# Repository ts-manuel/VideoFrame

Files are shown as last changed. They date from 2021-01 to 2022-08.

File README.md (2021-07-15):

# Video Frame


<!-- TABLE OF CONTENTS -->
<details open="open">
  <summary>Table of Contents</summary>
  <ol>
    <li>
      <a href="#about-the-project">About The Project</a>
    </li>
    <li>
      <a href="#getting-started">Getting Started</a>
      <ul>
        <li><a href="#prerequisites">Prerequisites</a></li>
        <li><a href="#compiling">Compiling</a></li>
        <li><a href="#usb-bootloader">USB Bootloader</a></li>
      </ul>
    </li>
    <li><a href="#how-to-operate">How to Operate</a></li>
      <ul>
        <li><a href="#circuit-diagram">Circuit Diagram</a></li>
        <li><a href="#buttons">Buttons</a></li>
        <li><a href="#configuration-through-usb">Configuration through USB</a></li>
      </ul>
    <li><a href="#disclaimer">Disclaimer</a></li>
  </ol>
</details>

<!-- ABOUT THE PROJECT -->
## About The Project
This is a digital picture frame that plays movies at one frame per minute. Images appear on a [7-Color ePaper display](https://www.waveshare.com/5.65inch-e-paper-module-f.htm). The whole movie is stored as a sequence of jpeg images on an SD-Card. An STM32 microcontroller does the jpeg decoding and drives the display.

e-Paper displays maintain the displayed image without needing any power. The image is updated every 24 minutes and an update cycle takes 18 seconds. Since the device is in sleep mode for the majority of the time, power draw is minimal and the batteries last for a decent amount of time.

The device is powered by 6 AA batteries.

For more info check out the [full log on hackaday.io](https://hackaday.io/project/177197-the-slowest-video-player-with-7-colors)

<!-- GETTING STARTED -->
## Getting Started
### Prerequisites
* [STM32CubeIDE 1.4.0](https://www.st.com/en/development-tools/stm32cubeide.html)
* [dfu-util](http://dfu-util.sourceforge.net/)

### Compiling
* Open STM32CubeIDE
* Select a folder as workspace (this can be any folder in your hard-drive)
* Click on `File > Import`
* Select `General > Existing Project into Workspace` then click next
* Browse for the folder `stm32` select the project and click finish

### USB bootloader
* Connect the USB cable, check that the [correct drivers](https://www.hanselman.com/blog/how-to-fix-dfuutil-stm-winusb-zadig-bootloaders-and-other-firmware-flashing-issues-on-windows) are installed
* Enter DFU mode by pressing the RESET while holding down the BOOT button
* Use the following command to flash the firmware

      dfu-util -a0 -s 0x08000000 0 -D "Video Frame.bin"

<!-- HOW TO OPERATE -->
## How to Operate
### Circuit Diagram
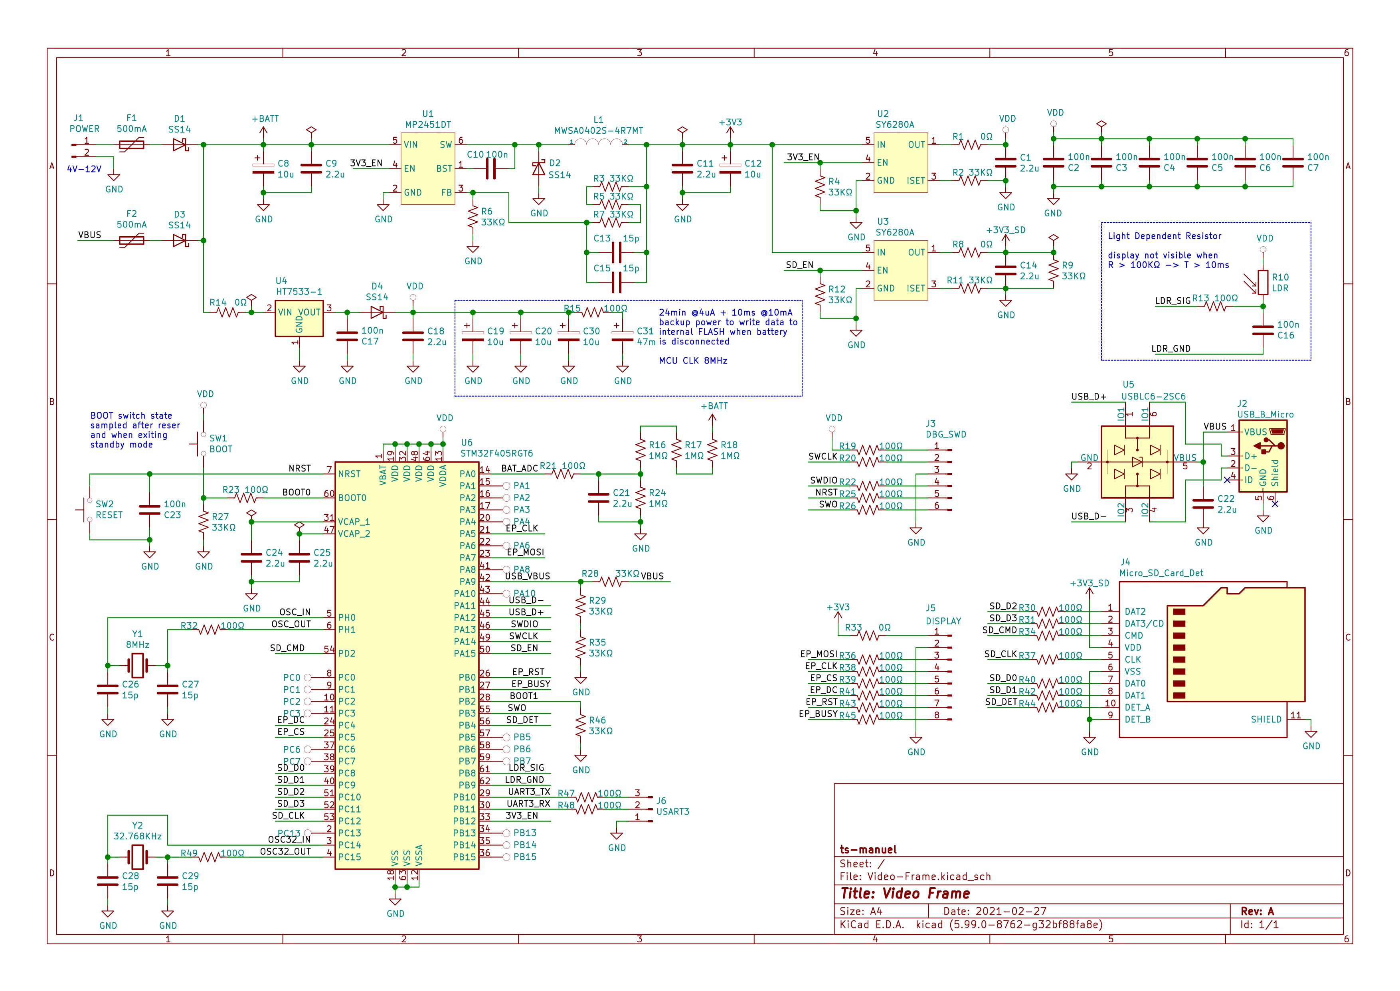
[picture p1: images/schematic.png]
Schematic


### Buttons
* **RESET**: Press during sleep to wake the microcontroller and initiate a display update cycle.
* **BOOT**: Hold down during reset to enter DFU mode. Press during display update to receive commands from the serial port.

### Configuration through USB
The USB emulates a serial port that can be used to configure the device. During normal operation, a timer interrupt wakes the microcontroller every 24 minutes to update the display. An update cycle can also be triggered by pressing the **RESET** button. By default, the microcontroller goes back into sleep mode immediately after the display has been updated. By pressing the **BOOT** button while the display is updating, the microcontroller starts listening for commands on the serial port. After 60 seconds of inactivity, the microcontroller goes back to sleep.

The following is a list of commands that can be entered.
> ***load FOLDER/FILE.jpg*** loads the specified file from the SD card

> ***update*** triggers an update cycle

> ***sleep*** enters sleep mode immediately

<!-- DISCLAIMER -->
## Disclaimer
The following project is shared "as is", with the sole objective of being useful. The creator of the described piece of hardware and its associated software cannot guarantee its correct functioning under any circumstance. The author of this project will not be held responsible for any material, personal or economic losses to you or any third parties that may arise from using this design. This project will not be used under any circumstances on systems whose responsibility is critical, or from which people's lives depend upon, directly or indirectly.

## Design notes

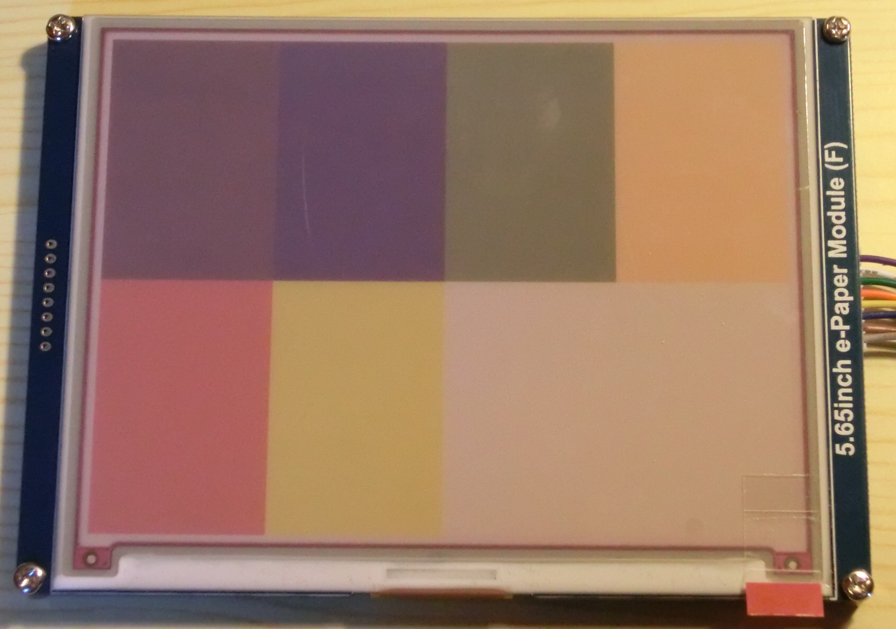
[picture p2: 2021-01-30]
images/display.jpg

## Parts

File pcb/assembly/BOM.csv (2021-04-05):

Comment | Designator | Footprint | LCSC
2.2u | C1,C9,C11,C14,C18,C21,C22,C24,C25 | Capacitor_SMD:C_0603_1608Metric | C23630
15p | C13,C15,C26,C27,C28,C29 | Capacitor_SMD:C_0603_1608Metric | C1644
100n | C2,C3,C4,C5,C6,C7,C10,C16,C17,C23 | Capacitor_SMD:C_0603_1608Metric | C14663
47m | C31 | Capacitor_SMD:CP_Elec_10x7.7 | FC0H473ZFTBR24
10u | C8,C12,C19,C20,C30 | Capacitor_Tantalum_SMD:CP_EIA-3216-10_Kemet-I | C7171
SS14 | D1,D2,D3,D4 | Diode_SMD:D_SMA | C2480
500mA | F1,F2 | Fuse:Fuse_1812_4532Metric | C269127
POWER | J1 | Connector_PinHeader_2.54mm:PinHeader_1x02_P2.54mm_Vertical | -
USB_B_Micro | J2 | Connector_MicroUSB:USB_Micro-B_CUI_Devices-UJ2-MIBH-G-SMT-TR | -
DBG_SWD | J3 | Connector_PinHeader_2.54mm:PinHeader_1x06_P2.54mm_Vertical | -
Micro_SD_Card_Det | J4 | Connector_Card:microSD_HC_Molex_104031-0811 | -
DISPLAY | J5 | Connector_PinHeader_2.54mm:PinHeader_1x08_P2.54mm_Horizontal | -
USART3 | J6 | Connector_PinHeader_2.54mm:PinHeader_1x03_P2.54mm_Vertical | -
MWSA0402S-4R7MT | L1 | Inductor_SMD:L_Murata_LQH55DN_5.7x5.0mm | C408337
0Ω | R1,R8,R14,R33 | Resistor_SMD:R_0603_1608Metric | C21189
LDR | R10 | OptoDevice:R_LDR_5.1x4.3mm_P3.4mm_Vertical | -
100Ω | R13,R15,R19,R20,R21,R22,R23,R25,R26,R30,R31,R32,R34,R36,R37,R38,R39,R40,R41,R42,R43,R44,R45,R47,R48,R49 | Resistor_SMD:R_0603_1608Metric | C22775
1MΩ | R16,R17,R18,R24 | Resistor_SMD:R_0603_1608Metric | C22935
33KΩ | R2,R3,R4,R5,R6,R7,R9,R11,R12,R27,R28,R29,R35,R46 | Resistor_SMD:R_0603_1608Metric | C4216
BOOT | SW1 | Button_Switch_THT:SW_PUSH_6mm | -
RESET | SW2 | Button_Switch_THT:SW_PUSH_6mm | -
PA1 | TP1 | TestPoint:TestPoint_Pad_D1.0mm | -
PC2 | TP10 | TestPoint:TestPoint_Pad_D1.0mm | -
PC3 | TP11 | TestPoint:TestPoint_Pad_D1.0mm | -
PB5 | TP12 | TestPoint:TestPoint_Pad_D1.0mm | -
PC6 | TP13 | TestPoint:TestPoint_Pad_D1.0mm | -
PB6 | TP14 | TestPoint:TestPoint_Pad_D1.0mm | -
PC7 | TP15 | TestPoint:TestPoint_Pad_D1.0mm | -
PB7 | TP16 | TestPoint:TestPoint_Pad_D1.0mm | -
PC13 | TP17 | TestPoint:TestPoint_Pad_D1.0mm | -
PB13 | TP18 | TestPoint:TestPoint_Pad_D1.0mm | -
PB14 | TP19 | TestPoint:TestPoint_Pad_D1.0mm | -
PA2 | TP2 | TestPoint:TestPoint_Pad_D1.0mm | -
PB15 | TP20 | TestPoint:TestPoint_Pad_D1.0mm | -
PA3 | TP3 | TestPoint:TestPoint_Pad_D1.0mm | -
PA4 | TP4 | TestPoint:TestPoint_Pad_D1.0mm | -
PA6 | TP5 | TestPoint:TestPoint_Pad_D1.0mm | -
PA8 | TP6 | TestPoint:TestPoint_Pad_D1.0mm | -
PA10 | TP7 | TestPoint:TestPoint_Pad_D1.0mm | -
PC0 | TP8 | TestPoint:TestPoint_Pad_D1.0mm | -
PC1 | TP9 | TestPoint:TestPoint_Pad_D1.0mm | -
MP2451DT | U1 | Package_TO_SOT_SMD:SOT-23-6_Handsoldering | C14123
SY6280A | U2,U3 | Package_TO_SOT_SMD:SOT-23-5_HandSoldering | C207620
HT7533-1 | U4 | Package_TO_SOT_SMD:SOT-89-3 | C14289
USBLC6-2SC6 | U5 | Package_TO_SOT_SMD:SOT-23-6 | C7519
STM32F405RGT6 | U6 | Package_QFP:LQFP-64_10x10mm_P0.5mm | C15742
8MHz | Y1 | Crystal:Crystal_SMD_5032-2Pin_5.0x3.2mm | C115962
32.768KHz | Y2 | Crystal:Crystal_SMD_3215-2Pin_3.2x1.5mm | C32346

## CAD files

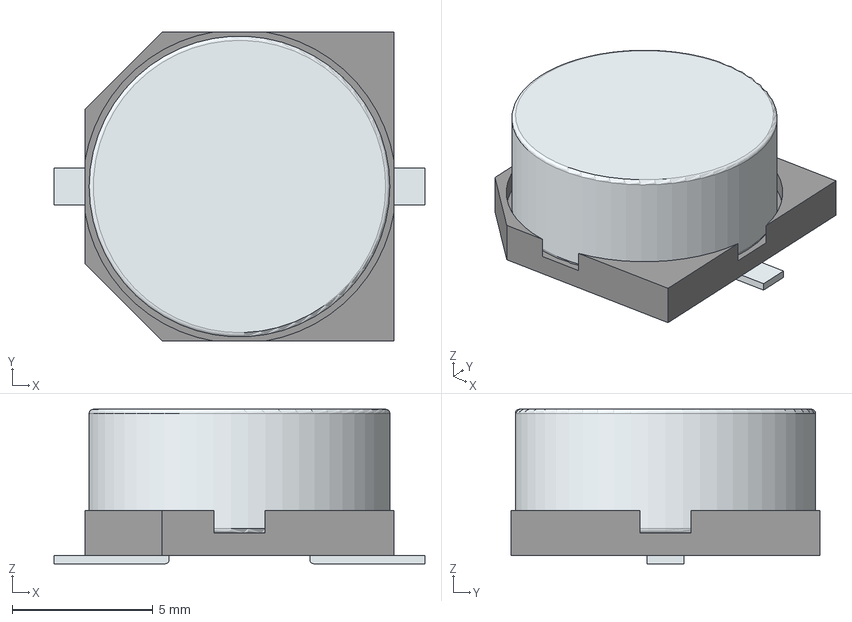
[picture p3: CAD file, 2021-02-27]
pcb/step/FC0H473ZFTBR24.stp
13.2 x 11.0 x 5.50 mm
Base
Pin1Fillet
Pin2Fillet

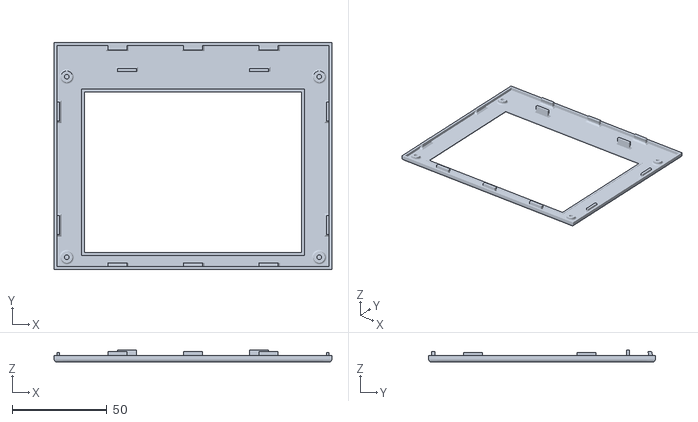
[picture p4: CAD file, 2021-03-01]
stl/Front.stl
147.0 x 120.1 x 6.50

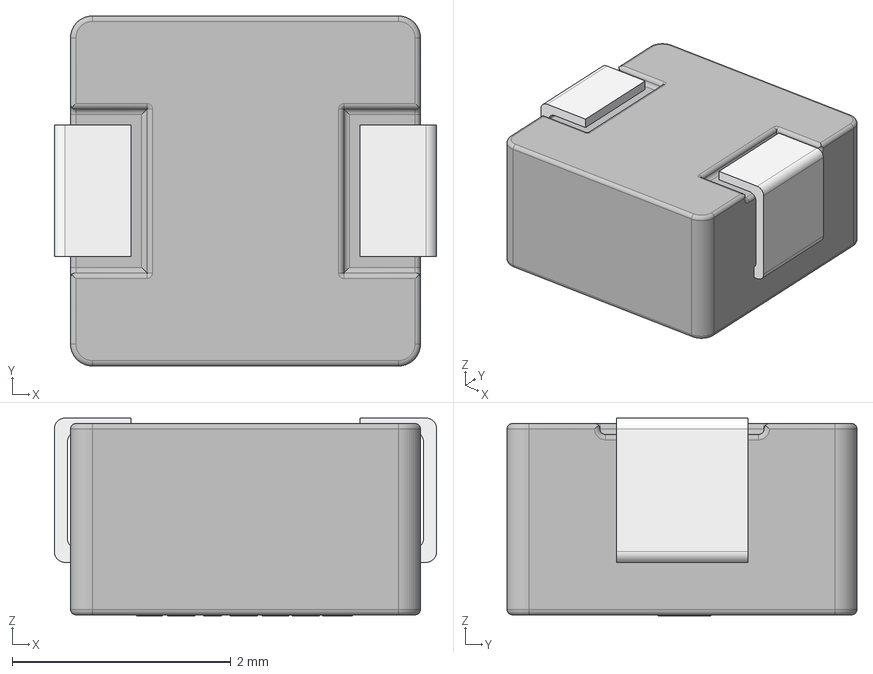
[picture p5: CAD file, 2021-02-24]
pcb/step/SRP3020TA.stp
3.50 x 3.20 x 1.81 mm

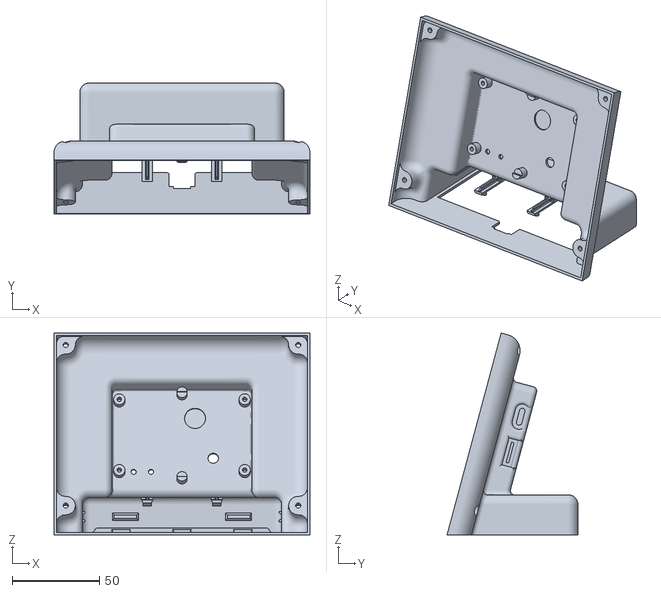
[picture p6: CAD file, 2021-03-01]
stl/Back.stl
147.0 x 75.2 x 116.0

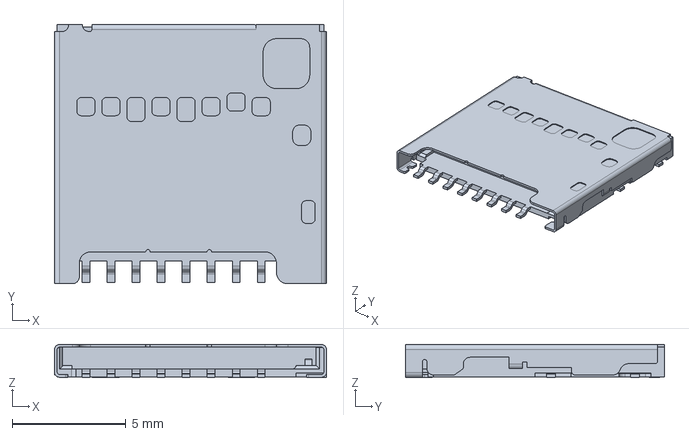
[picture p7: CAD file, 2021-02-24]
pcb/step/MicroSD_Molex_1040310811.stp
11.9 x 11.4 x 1.45 mm

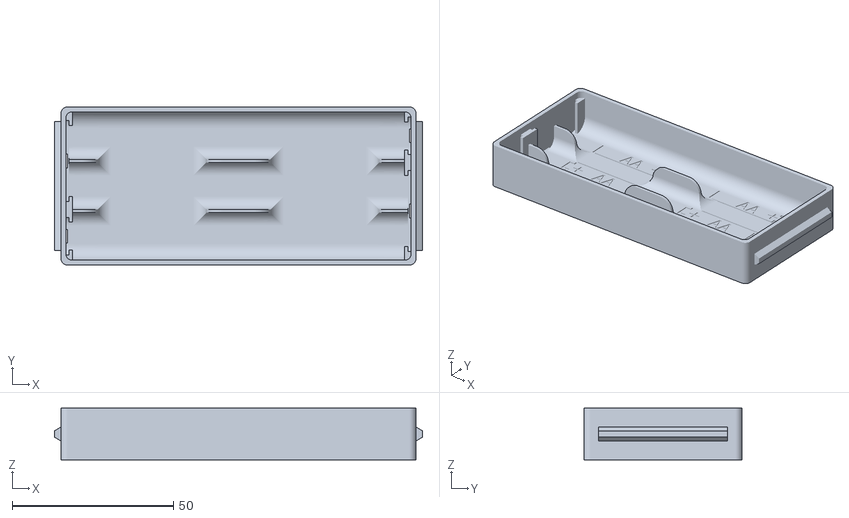
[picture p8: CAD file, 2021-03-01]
stl/BatteryHolder.stl
114.0 x 49.0 x 16.0

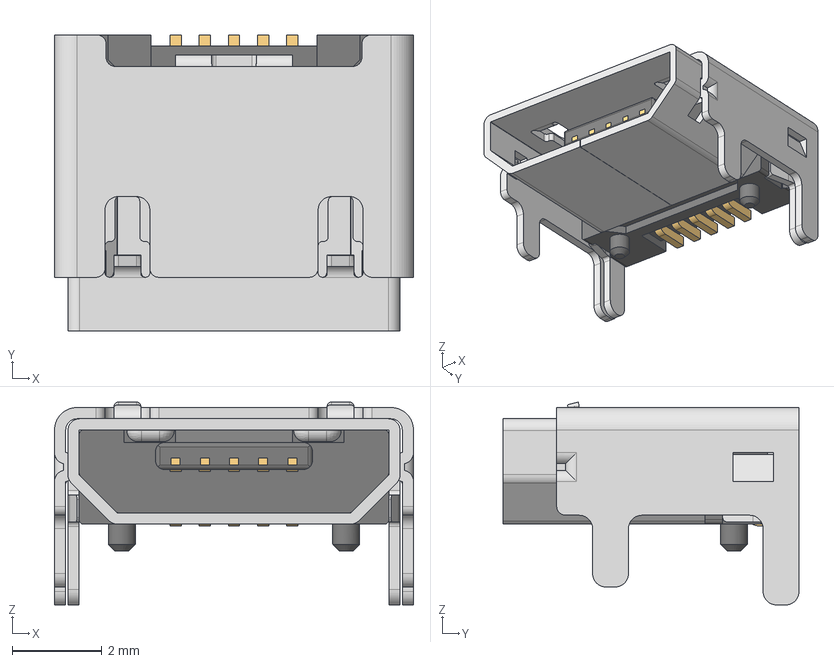
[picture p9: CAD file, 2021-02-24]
pcb/step/MicroUSB_Wurth Elektronik_629105150521.stp
8.00 x 6.60 x 4.52 mm
629105150521_Pin1 x 4
629105150521_Housing
629105150521_Pin2
629105150521_Shielding
629105150521_Shielding2

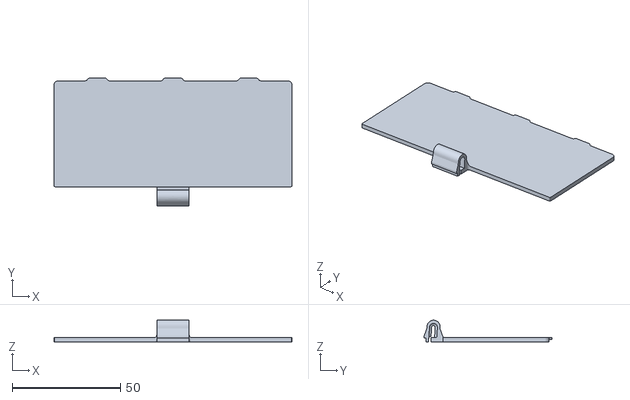
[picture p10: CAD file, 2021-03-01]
stl/BatteryCover.stl
110.0 x 59.0 x 10.00

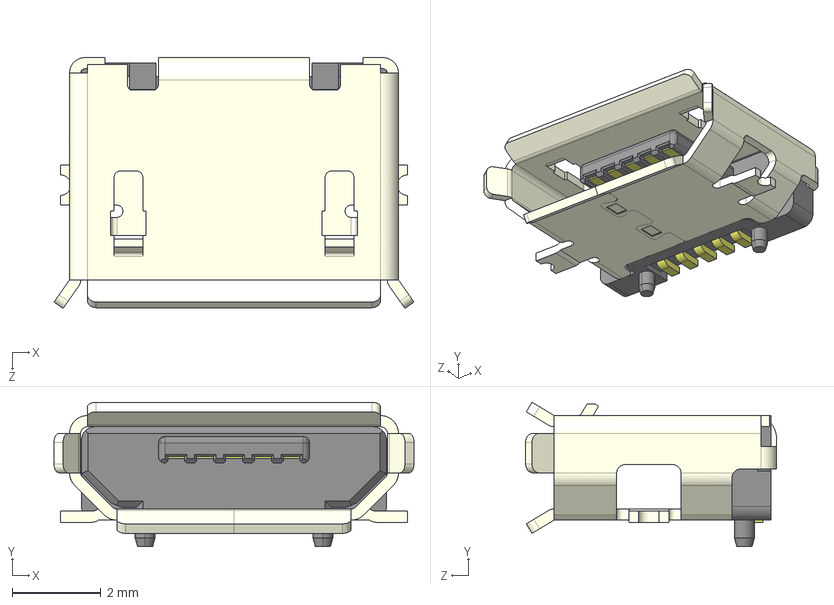
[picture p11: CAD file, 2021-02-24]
pcb/step/CUI_DEVICES_UJ2-MIBH-G-SMT-TR.stp
8.10 x 3.25 x 5.64 mm

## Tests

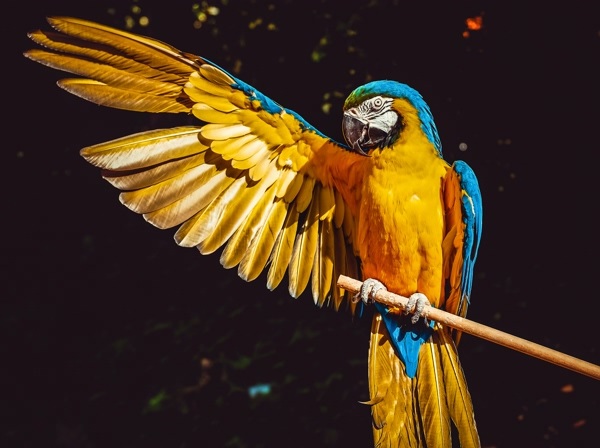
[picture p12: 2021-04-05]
test_files/bird.jpg

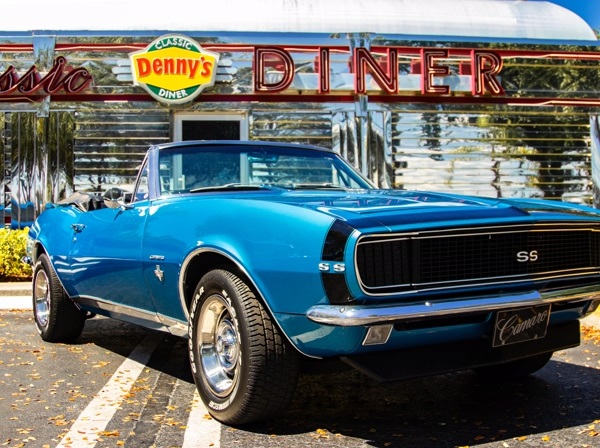
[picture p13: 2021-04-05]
test_files/car.jpg

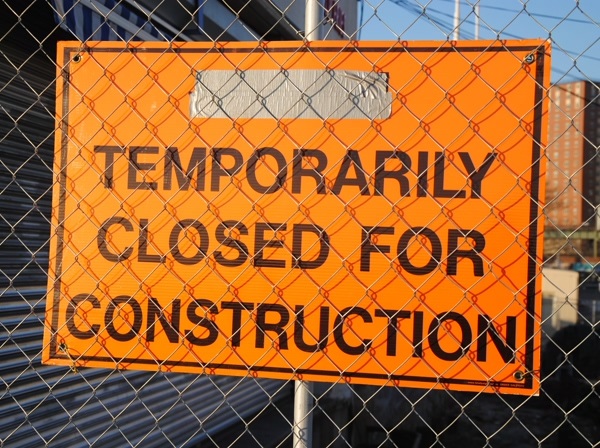
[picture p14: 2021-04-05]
test_files/sign.jpg

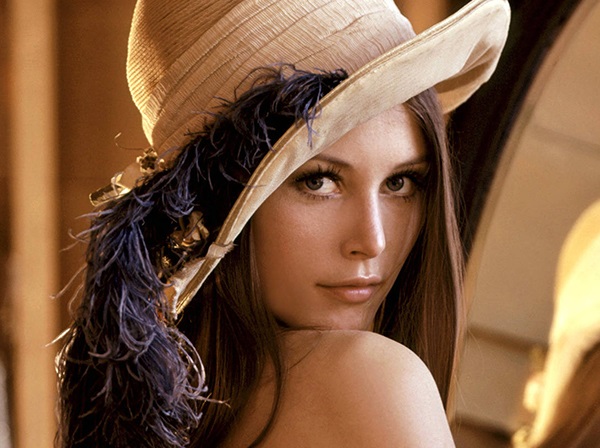
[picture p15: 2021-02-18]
test_files/lena.jpg

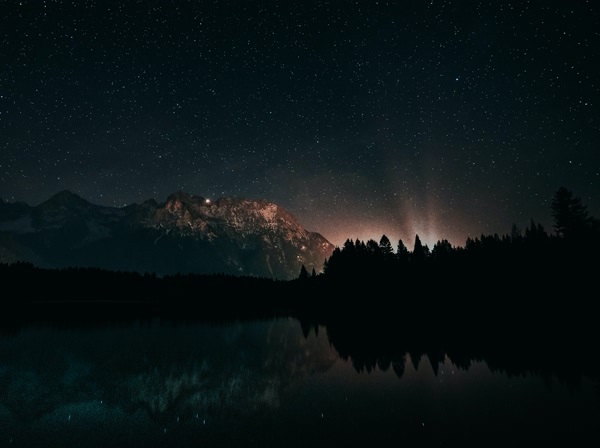
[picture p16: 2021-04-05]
test_files/lake.jpg

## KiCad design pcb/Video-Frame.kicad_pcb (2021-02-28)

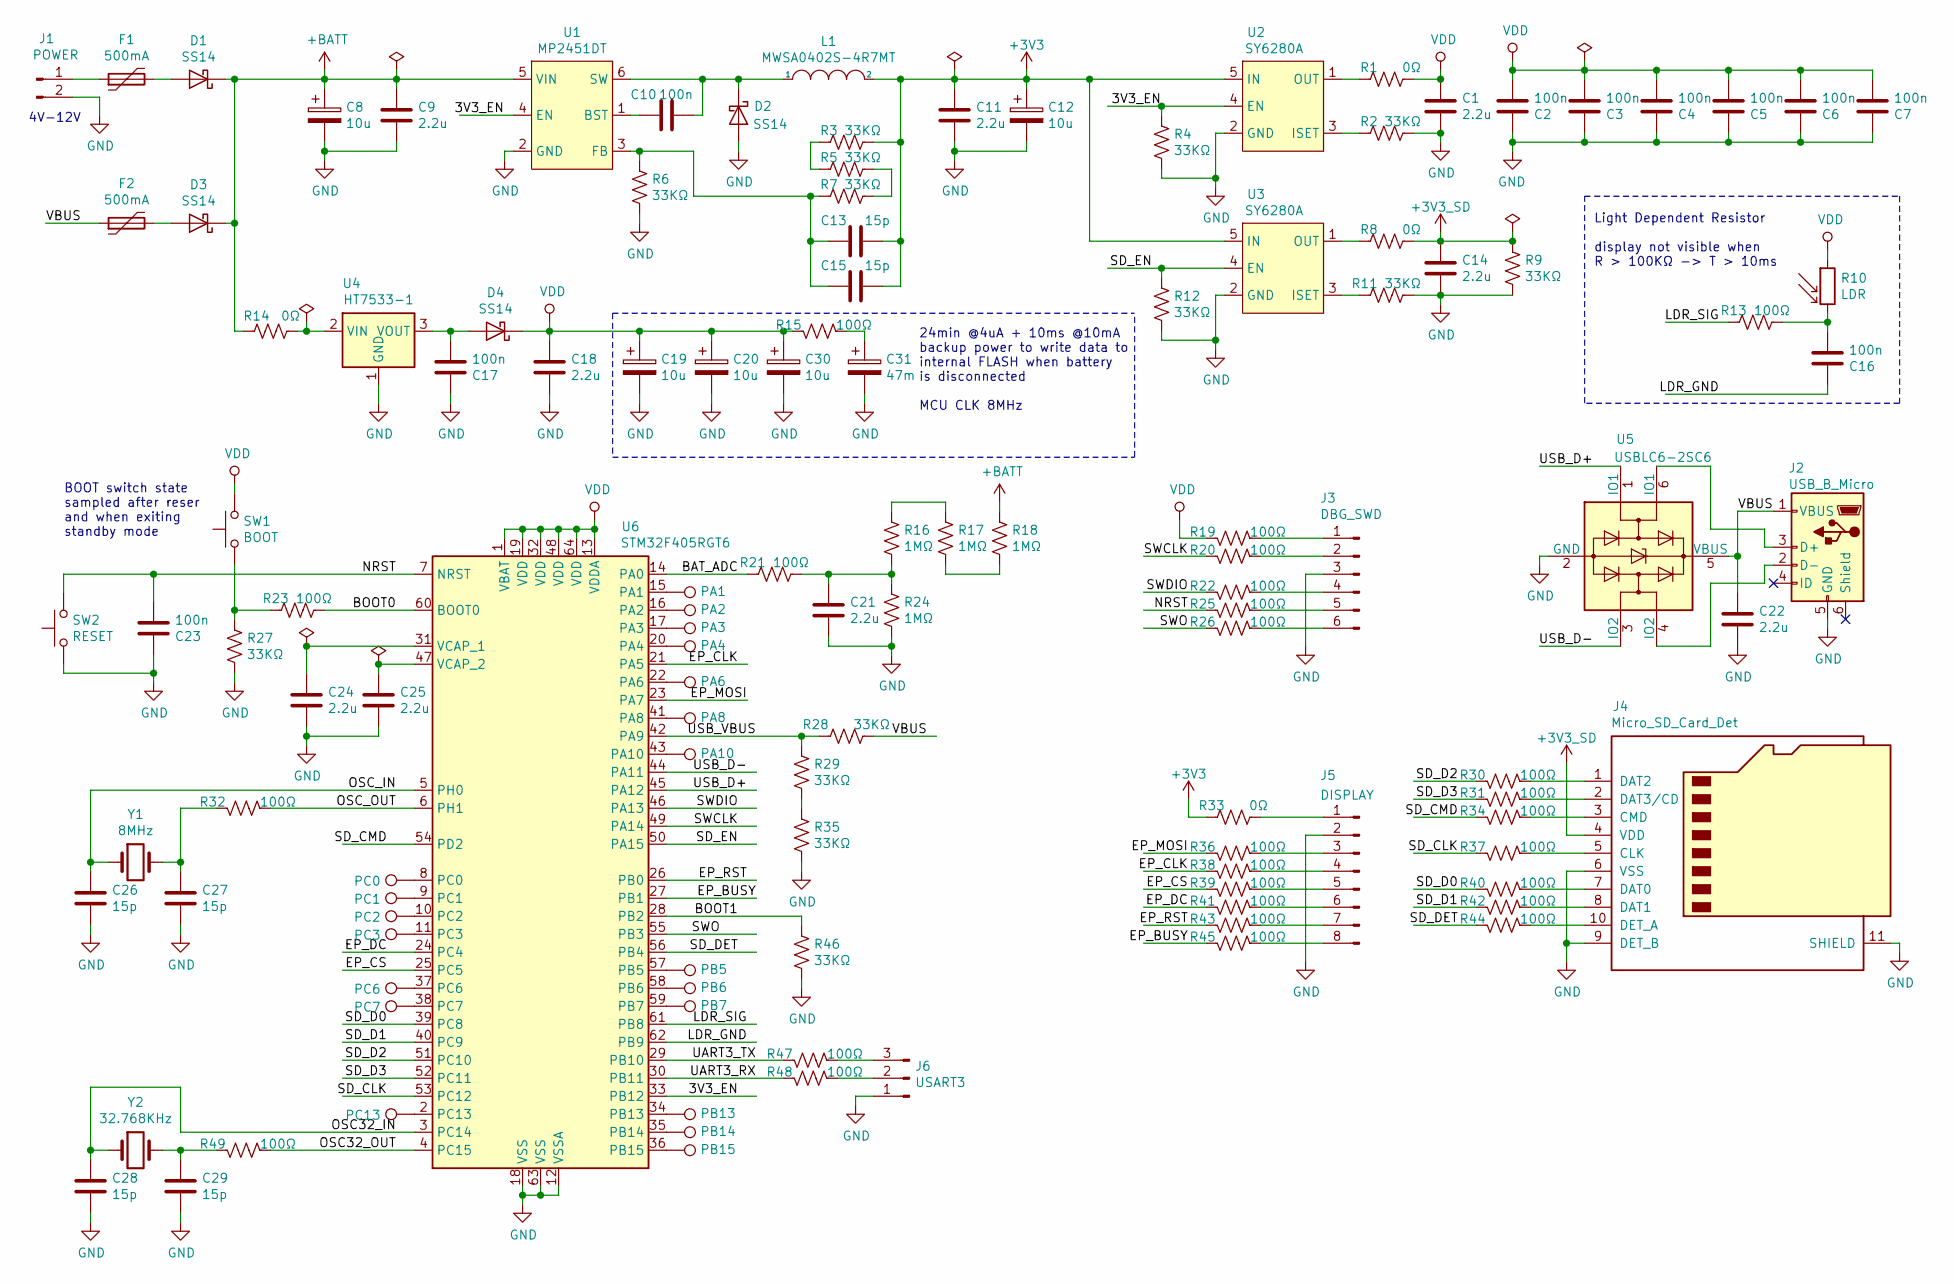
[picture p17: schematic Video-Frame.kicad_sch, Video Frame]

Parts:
C1, C9, C11, C14, C18, C21, C22, C24, C25: 2.2u; C_0603_1608Metric; LCSC Footprint 0603
C2, C3, C4, C5, C6, C7, C10, C16, C17, C23: 100n; C_0603_1608Metric; LCSC Footprint 0603
C8, C12, C19, C20, C30: 10u; CP_EIA-3216-10_Kemet-I; LCSC Footprint CASE-A_3216
C13, C15, C26, C27, C28, C29: 15p; C_0603_1608Metric; LCSC Footprint 0603
C31: 47m; CP_Elec_10x7.7; LCSC FC0H473ZFTBR24
D1, D2, D3, D4: SS14; D_SMA; LCSC Footprint SMA,DO-214AC
F1, F2: 500mA; Fuse_1812_4532Metric; LCSC C269127
J1: POWER; PinHeader_1x02_P2.54mm_Vertical
J2: USB_B_Micro; USB_Micro-B_CUI_Devices-UJ2-MIBH-G-SMT-TR
J3: DBG_SWD; PinHeader_1x06_P2.54mm_Vertical
J4: Micro_SD_Card_Det; microSD_HC_Molex_104031-0811
J5: DISPLAY; PinHeader_1x08_P2.54mm_Horizontal
J6: USART3; PinHeader_1x03_P2.54mm_Vertical
L1: MWSA0402S-4R7MT; L_Murata_LQH55DN_5.7x5.0mm; LCSC Footprint SMD-4.2x4.4x2.0
R1, R8, R14, R33: 0Ω; R_0603_1608Metric; LCSC Footprint 0603
R2, R3, R4, R5, R6, R7, R9, R11, R12, R27, R28, R29, R35, R46: 33KΩ; R_0603_1608Metric; LCSC Footprint 0603
R10: LDR; R_LDR_5.1x4.3mm_P3.4mm_Vertical
R13, R15, R19, R20, R21, R22, R23, R25, R26, R30, R31, R32, R34, R36, R37, R38, R39, R40, R41, R42, R43, R44, R45, R47, R48, R49: 100Ω; R_0603_1608Metric; LCSC Footprint 0603
R16, R17, R18, R24: 1MΩ; R_0603_1608Metric; LCSC Footprint 0603
SW1: BOOT; SW_PUSH_6mm
SW2: RESET; SW_PUSH_6mm
TP1: PA1; TestPoint_Pad_D1.0mm
TP2: PA2; TestPoint_Pad_D1.0mm
TP3: PA3; TestPoint_Pad_D1.0mm
TP4: PA4; TestPoint_Pad_D1.0mm
TP5: PA6; TestPoint_Pad_D1.0mm
TP6: PA8; TestPoint_Pad_D1.0mm
TP7: PA10; TestPoint_Pad_D1.0mm
TP8: PC0; TestPoint_Pad_D1.0mm
TP9: PC1; TestPoint_Pad_D1.0mm
TP10: PC2; TestPoint_Pad_D1.0mm
TP11: PC3; TestPoint_Pad_D1.0mm
TP12: PB5; TestPoint_Pad_D1.0mm
TP13: PC6; TestPoint_Pad_D1.0mm
TP14: PB6; TestPoint_Pad_D1.0mm
TP15: PC7; TestPoint_Pad_D1.0mm
TP16: PB7; TestPoint_Pad_D1.0mm
TP17: PC13; TestPoint_Pad_D1.0mm
TP18: PB13; TestPoint_Pad_D1.0mm
TP19: PB14; TestPoint_Pad_D1.0mm
TP20: PB15; TestPoint_Pad_D1.0mm
U1: MP2451DT; SOT-23-6_Handsoldering; LCSC Footprint SOT-23-6L
U2, U3: SY6280A; SOT-23-5_HandSoldering; LCSC Footprint SOT-23-5
U4: HT7533-1; SOT-89-3; LCSC Footprint SOT-89-3
U5: USBLC6-2SC6; SOT-23-6; LCSC Footprint SOT-23-6L
U6: STM32F405RGT6; LQFP-64_10x10mm_P0.5mm; LCSC Footprint LQFP-64_10.0x10.0x0.5P
Y1: 8MHz; Crystal_SMD_5032-2Pin_5.0x3.2mm; LCSC Footprint SMD-5032_2P
Y2: 32.768KHz; Crystal_SMD_3215-2Pin_3.2x1.5mm; LCSC Footprint SMD-3215_2P

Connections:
+3V3: C11.1, C12.1, C13.2, C15.2, L1.2, R3.2, R33.1, U2.5 (IN), U3.5 (IN)
+3V3_SD: C14.1, J4.4 (VDD), R8.2, R9.1
+BATT: C8.1, C9.1, D1.1 (K), D3.1 (K), R14.2, R18.1, U1.5 (VIN)
/3V3_EN: R4.1, U1.4 (EN), U2.4 (EN), U6.33 (PB12)
/BAT_ADC: R21.1, U6.14 (PA0)
/BOOT0: R23.2, U6.60 (BOOT0)
/BOOT1: R46.1, U6.28 (PB2)
/EP_BUSY: R45.1, U6.27 (PB1)
/EP_CLK: R38.1, U6.21 (PA5)
/EP_CS: R39.1, U6.25 (PC5)
/EP_DC: R41.1, U6.24 (PC4)
/EP_MOSI: R36.1, U6.23 (PA7)
/EP_RST: R43.1, U6.26 (PB0)
/LDR_GND: C16.1, U6.62 (PB9)
/LDR_SIG: R13.1, U6.61 (PB8)
/NRST: C23.2, R25.1, SW2.2, U6.7 (NRST)
/OSC32_IN: C28.1, U6.3 (PC14), Y2.1
/OSC32_OUT: R49.2, U6.4 (PC15)
/OSC_IN: C26.1, U6.5 (PH0), Y1.1
/OSC_OUT: R32.2, U6.6 (PH1)
/SD_CLK: R37.1, U6.53 (PC12)
/SD_CMD: R34.1, U6.54 (PD2)
/SD_D0: R40.1, U6.39 (PC8)
/SD_D1: R42.1, U6.40 (PC9)
/SD_D2: R30.1, U6.51 (PC10)
/SD_D3: R31.1, U6.52 (PC11)
/SD_DET: R44.1, U6.56 (PB4)
/SD_EN: R12.1, U3.4 (EN), U6.50 (PA15)
/SWCLK: R20.1, U6.49 (PA14)
/SWDIO: R22.1, U6.46 (PA13)
/SWO: R26.1, U6.55 (PB3)
/UART3_RX: R48.1, U6.30 (PB11)
/UART3_TX: R47.1, U6.29 (PB10)
/USB_D+: U5.1 (IO1), U6.45 (PA12)
/USB_D-: U5.3 (IO2), U6.44 (PA11)
/USB_VBUS: R28.1, R29.1, U6.42 (PA9)
/VBUS: C22.1, F2.1, J2.1 (VBUS), R28.2, U5.5 (VBUS)
GND: C1.2, C2.1, C3.1, C4.1, C5.1, C6.1, C7.1, C8.2, C9.2, C11.2, C12.2, C14.2, C17.1, C18.2, C19.2, C20.2, C21.2, C22.2, C23.1, C24.2, C25.2, C26.2, C27.2, C28.2, C29.2, C30.2, C31.2, D2.2 (A), J1.2, J2.5 (GND), J3.3, J4.6 (VSS), J4.9 (DET_B), J4.11 (SHIELD), J5.2, J6.1, R2.2, R4.2, R6.2, R9.2, R11.2, R12.2, R24.2, R27.2, R35.2, R46.2, SW2.1, U1.2 (GND), U2.2 (GND), U3.2 (GND), U4.1 (GND), U5.2 (GND), U6.12 (VSSA), U6.18 (VSS), U6.63 (VSS)
unnamed: C10.1, D2.1 (K), L1.1, U1.6 (SW)
unnamed: C10.2, U1.1 (BST)
unnamed: C13.1, C15.1, R6.1, R7.1, U1.3 (FB)
unnamed: C16.2, R10.2, R13.2
unnamed: C17.2, D4.2 (A), U4.3 (VOUT)
unnamed: C21.1, R16.2, R21.2, R24.1
unnamed: C24.1, U6.31 (VCAP_1)
unnamed: C25.1, U6.47 (VCAP_2)
unnamed: C27.1, R32.1, Y1.2
unnamed: C29.1, R49.1, Y2.2
unnamed: C31.1, R15.2
unnamed: D1.2 (A), F1.2
unnamed: D3.2 (A), F2.2
unnamed: F1.1, J1.1
unnamed: J2.2 (D-), U5.4 (IO2)
unnamed: J2.3 (D+), U5.6 (IO1)
unnamed: J3.1, R19.2
unnamed: J3.2, R20.2
unnamed: J3.4, R22.2
unnamed: J3.5, R25.2
unnamed: J3.6, R26.2
unnamed: J4.1 (DAT2), R30.2
unnamed: J4.2 (DAT3/CD), R31.2
unnamed: J4.3 (CMD), R34.2
unnamed: J4.5 (CLK), R37.2
unnamed: J4.7 (DAT0), R40.2
unnamed: J4.8 (DAT1), R42.2
unnamed: J4.10 (DET_A), R44.2
unnamed: J5.1, R33.2
unnamed: J5.3, R36.2
unnamed: J5.4, R38.2
unnamed: J5.5, R39.2
unnamed: J5.6, R41.2
unnamed: J5.7, R43.2
unnamed: J5.8, R45.2
unnamed: J6.2, R48.2
unnamed: J6.3, R47.2
unnamed: R1.1, U2.1 (OUT)
unnamed: R2.1, U2.3 (ISET)
unnamed: R3.1, R5.1
unnamed: R5.2, R7.2
unnamed: R8.1, U3.1 (OUT)
unnamed: R11.1, U3.3 (ISET)
unnamed: R16.1, R17.1
unnamed: R17.2, R18.2
unnamed: R23.1, R27.1, SW1.1
unnamed: R29.2, R35.1
unnamed: TP1.1, U6.15 (PA1)
unnamed: TP2.1, U6.16 (PA2)
unnamed: TP3.1, U6.17 (PA3)
unnamed: TP4.1, U6.20 (PA4)
unnamed: TP5.1, U6.22 (PA6)
unnamed: TP6.1, U6.41 (PA8)
unnamed: TP7.1, U6.43 (PA10)
unnamed: TP8.1, U6.8 (PC0)
unnamed: TP9.1, U6.9 (PC1)
unnamed: TP10.1, U6.10 (PC2)
unnamed: TP11.1, U6.11 (PC3)
unnamed: TP12.1, U6.57 (PB5)
unnamed: TP13.1, U6.37 (PC6)
unnamed: TP14.1, U6.58 (PB6)
unnamed: TP15.1, U6.38 (PC7)
unnamed: TP16.1, U6.59 (PB7)
unnamed: TP17.1, U6.2 (PC13)
unnamed: TP18.1, U6.34 (PB13)
unnamed: TP19.1, U6.35 (PB14)
unnamed: TP20.1, U6.36 (PB15)
unnamed: R14.1, U4.2 (VIN)
VDD: C1.1, C2.2, C3.2, C4.2, C5.2, C6.2, C7.2, C18.1, C19.1, C20.1, C30.1, D4.1 (K), R1.2, R10.1, R15.1, R19.1, SW1.2, U6.1 (VBAT), U6.13 (VDDA), U6.19 (VDD), U6.32 (VDD), U6.48 (VDD), U6.64 (VDD)

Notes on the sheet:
BOOT switch state sampled after reser and when exiting standby mode
4V-12V
24min @4uA + 10ms @10mA backup power to write data to internal FLASH when battery is disconnected MCU CLK 8MHz
Light Dependent Resistor display not visible when R > 100KΩ -> T > 10ms

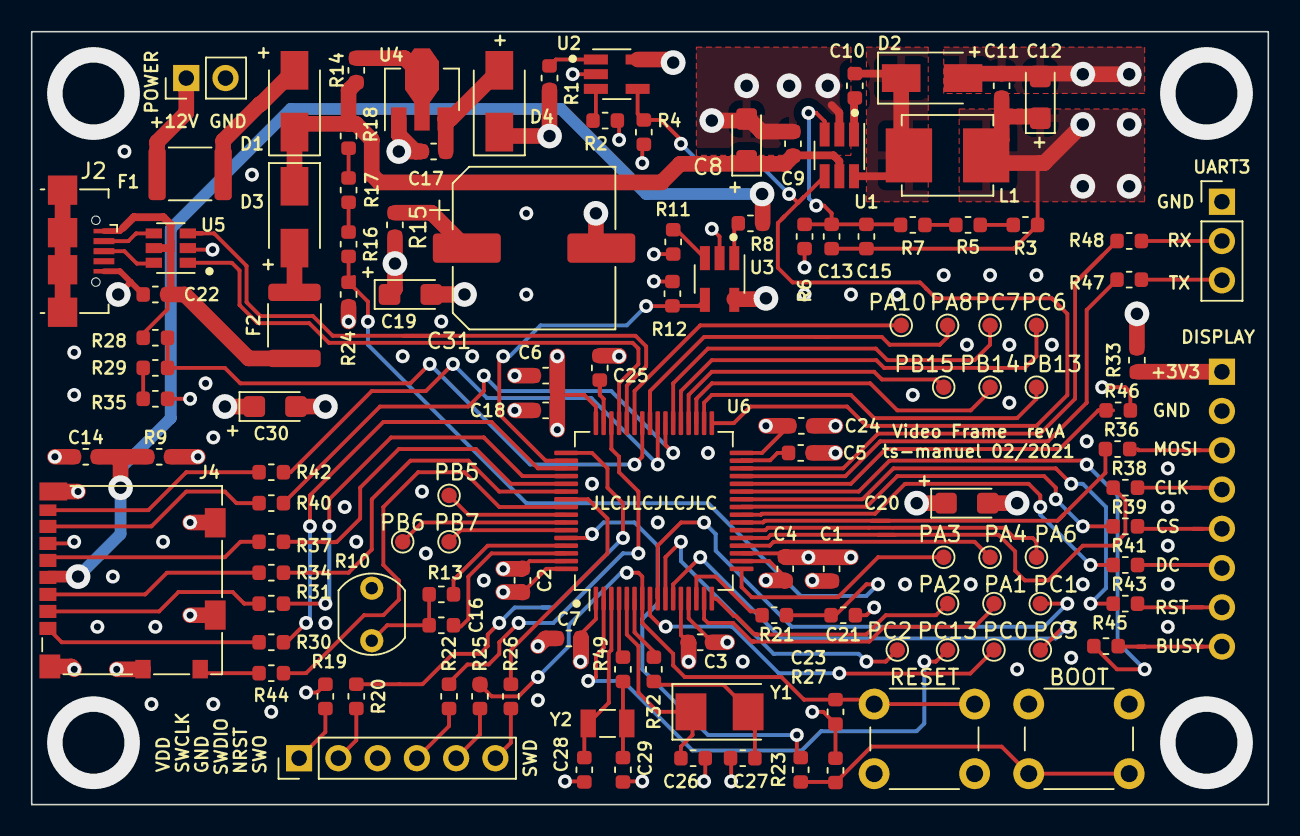
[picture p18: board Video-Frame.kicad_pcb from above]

Board: 4 copper layers, 80.0 x 50.0 mm, 123 parts (1 on the bottom side), 107 nets.

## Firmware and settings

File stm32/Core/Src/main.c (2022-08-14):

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

/* Includes ------------------------------------------------------------------*/
#include "main.h"
#include "cmsis_os.h"
#include "fatfs.h"
#include "usb_device.h"

/* USER CODE BEGIN Includes */
#include <stdio.h>
#include <stdlib.h>
#include <ctype.h>
#include <stdbool.h>
#include <stdint.h>
#include <string.h>

#include "hardware/power.h"
#include "hardware/sd.h"
#include "tasks/console_task.h"
#include "tasks/display_task.h"
/* USER CODE END Includes */

RTC_HandleTypeDef hrtc;

SD_HandleTypeDef hsd;
DMA_HandleTypeDef hdma_sdio_rx;
DMA_HandleTypeDef hdma_sdio_tx;

SPI_HandleTypeDef hspi1;

UART_HandleTypeDef huart3;

/* Definitions for consoleTask */
osThreadId_t consoleTaskHandle;
const osThreadAttr_t consoleTask_attributes = {
  .name = "consoleTask",
  .priority = (osPriority_t) osPriorityNormal,
  .stack_size = 1024 * 4
};
/* Definitions for displayTask */
osThreadId_t displayTaskHandle;
const osThreadAttr_t displayTask_attributes = {
  .name = "displayTask",
  .priority = (osPriority_t) osPriorityAboveNormal,
  .stack_size = 10000 * 4
};
/* USER CODE BEGIN PV */

FATFS fs;
ConsoleTaskArgs_t consoleTask_args;
DisplayTaskArgs_t displayTask_args;
volatile bool sleep_cmd_disabled = false;

/* USER CODE END PV */

void SystemClock_Config(void);
static void MX_GPIO_Init(void);
static void MX_DMA_Init(void);
static void MX_RTC_Init(void);
static void MX_SPI1_Init(void);
static void MX_SDIO_SD_Init(void);
static void MX_USART3_UART_Init(void);
void StartConsoleTask(void *argument);
extern void StartDisplayTask(void *argument);

/* USER CODE BEGIN 0 */

/*
 * Called when an EXTI interrupt is triggered
 * */
void HAL_GPIO_EXTI_Callback(uint16_t GPIO_Pin)
{
	if(GPIO_Pin & BTN_SLEEP_Pin)
	{
		sleep_cmd_disabled = true;
	}
}

/* USER CODE END 0 */

/**
  * @brief  The application entry point.
  * @retval int
  */
int main(void)
{
  /* USER CODE BEGIN 1 */
  /*
   * The stack frame for main is reused when osKernelStart(); i called
   * DO NOT allocate variables in this stack frame if they are used
   * after osKernelStart(); (for example as task arguments)
   * */

  /* USER CODE END 1 */

  /* MCU Configuration--------------------------------------------------------*/

  /* Reset of all peripherals, Initializes the Flash interface and the Systick. */
  HAL_Init();

  /* Configure the system clock */
  SystemClock_Config();

  /* Initialize all configured peripherals */
  MX_GPIO_Init();
  MX_DMA_Init();
  MX_RTC_Init();
  MX_SPI1_Init();
  MX_FATFS_Init();
  MX_SDIO_SD_Init();
  MX_USART3_UART_Init();
  /* USER CODE BEGIN 2 */

  //Enable power
  printf("Enabling power\n");
  PWR_Enable(PWR_3V3);
  HAL_Delay(100);

  //Flash LED0 on startup
  for(int i = 0; i < 4; i++)
  {
	HAL_GPIO_TogglePin(LED0_GPIO_Port, LED0_Pin);
  	HAL_Delay(250);
  }

  //Load startup commands
  const char* cmd_str = "update\n""sleep\n";
  if(!InitCMDBuffer(cmd_str))
	  printf("ERROR: CMD string too long for buffer\n");

  /* USER CODE END 2 */

  /* Init scheduler */
  osKernelInitialize();

  /* USER CODE BEGIN RTOS_MUTEX */
  /* add mutexes, ... */
  /* USER CODE END RTOS_MUTEX */

  /* USER CODE BEGIN RTOS_SEMAPHORES */
  /* add semaphores, ... */
  /* USER CODE END RTOS_SEMAPHORES */

  /* USER CODE BEGIN RTOS_TIMERS */
  /* start timers, add new ones, ... */
  /* USER CODE END RTOS_TIMERS */

  /* USER CODE BEGIN RTOS_QUEUES */
  /* add queues, ... */
  displayTask_args.message_queue =  osMessageQueueNew(1, sizeof(DisplayMessage_t), NULL);
  /* USER CODE END RTOS_QUEUES */

  /* Create the thread(s) */
  /* creation of consoleTask */
  consoleTaskHandle = osThreadNew(StartConsoleTask, (void*)&consoleTask_args, &consoleTask_attributes);

  /* creation of displayTask */
  displayTaskHandle = osThreadNew(StartDisplayTask, (void*)&displayTask_args, &displayTask_attributes);

  /* USER CODE BEGIN RTOS_THREADS */

  consoleTask_args.huart = &huart3;
  consoleTask_args.displayTaskId = displayTaskHandle;
  consoleTask_args.display_message_queue = displayTask_args.message_queue;
  consoleTask_args.sleep_cmd_disabled = &sleep_cmd_disabled;

  /* USER CODE END RTOS_THREADS */

  /* Start scheduler */
  osKernelStart();

  /* We should never get here as control is now taken by the scheduler */
  /* Infinite loop */
  /* USER CODE BEGIN WHILE */
  while (1)
  {
    /* USER CODE END WHILE */

    /* USER CODE BEGIN 3 */
  }
  /* USER CODE END 3 */
}

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
/* USER CODE BEGIN Header_StartConsoleTask */
/**
  * @brief  Function implementing the consoleTask thread.
  * @param  argument: Not used
  * @retval None
  */
/* USER CODE END Header_StartConsoleTask */
__weak void StartConsoleTask(void *argument)
{
  /* init code for USB_DEVICE */
  MX_USB_DEVICE_Init();
  /* USER CODE BEGIN 5 */

  /* Infinite loop */
  for(;;)
  {
    osDelay(1);
  }
  /* USER CODE END 5 */
}

 /**
  * @brief  Period elapsed callback in non blocking mode
  * @note   This function is called  when TIM1 interrupt took place, inside
  * HAL_TIM_IRQHandler(). It makes a direct call to HAL_IncTick() to increment
  * a global variable "uwTick" used as application time base.
  * @param  htim : TIM handle
  * @retval None
  */
void HAL_TIM_PeriodElapsedCallback(TIM_HandleTypeDef *htim)
{
  if (htim->Instance == TIM1) {
    HAL_IncTick();
  }
}

/**
  * @brief  This function is executed in case of error occurrence.
  * @retval None
  */
void Error_Handler(void)
{
  /* USER CODE BEGIN Error_Handler_Debug */
  /* User can add his own implementation to report the HAL error return state */

  /* USER CODE END Error_Handler_Debug */
}

#ifdef  USE_FULL_ASSERT
/**
  * @brief  Reports the name of the source file and the source line number
  *         where the assert_param error has occurred.
  * @param  file: pointer to the source file name
  * @param  line: assert_param error line source number
  * @retval None
  */
void assert_failed(uint8_t *file, uint32_t line)
{
  /* USER CODE BEGIN 6 */
  /* User can add his own implementation to report the file name and line number,
     tex: printf("Wrong parameters value: file %s on line %d\r\n", file, line) */
  /* USER CODE END 6 */
}
#endif /* USE_FULL_ASSERT */

/************************ (C) COPYRIGHT STMicroelectronics *****END OF FILE****/

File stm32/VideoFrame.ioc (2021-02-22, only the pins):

Mcu.UserName=STM32F405RGTx
PA0-WKUP.Signal=ADCx_IN0
PA11.Signal=USB_OTG_FS_DM
PA12.Signal=USB_OTG_FS_DP
PA13.Signal=SYS_JTMS-SWDIO
PA14.Signal=SYS_JTCK-SWCLK
PA15.GPIO_Label=PWR_SD_EN
PA15.Signal=GPIO_Output
PA5.GPIO_Label=EP_CLK
PA5.Signal=SPI1_SCK
PA7.GPIO_Label=EP_MOSI
PA7.Signal=SPI1_MOSI
PA9.Signal=USB_OTG_FS_VBUS
PB0.GPIO_Label=EP_RST
PB0.Signal=GPIO_Output
PB1.GPIO_Label=EP_BUSY
PB1.Signal=GPIO_Input
PB10.GPIO_Label=UART3_TX
PB10.Signal=USART3_TX
PB11.GPIO_Label=UART3_RX
PB11.Signal=USART3_RX
PB12.GPIO_Label=PWR_3V3_EN
PB12.Signal=GPIO_Output
PB3.Signal=SYS_JTDO-SWO
PB4.GPIO_Label=SD_DET
PB4.Signal=GPIO_Input
PB8.GPIO_Label=LDR_SIG
PB8.Signal=GPIO_Input
PB9.GPIO_Label=LDR_GND
PB9.Signal=GPIO_Output
PC10.Signal=SDIO_D2
PC11.Signal=SDIO_D3
PC12.Signal=SDIO_CK
PC14-OSC32_IN.Signal=RCC_OSC32_IN
PC15-OSC32_OUT.Signal=RCC_OSC32_OUT
PC4.GPIO_Label=EP_DC
PC4.Signal=GPIO_Output
PC5.GPIO_Label=EP_CS
PC5.Signal=GPIO_Output
PC8.Signal=SDIO_D0
PC9.Signal=SDIO_D1
PD2.Signal=SDIO_CMD
PH0-OSC_IN.Signal=RCC_OSC_IN
PH1-OSC_OUT.Signal=RCC_OSC_OUT

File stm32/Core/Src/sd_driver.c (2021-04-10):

/**
 ******************************************************************************
 * @file      sd_driver.c
 * @author    ts-manuel
 * @brief     Driver for the SD-Card
 *
 ******************************************************************************
 */

#include "sd_driver.h"

#define _MAX_INIT_RETRY		100


/*
 * Initialize SD-Card
 * */
HAL_StatusTypeDef SD_Init(SD_HandleTypeDef* hsd, FATFS* fs)
{
	//Enable power
	PWR_Enable(PWR_SD);

	//Initialize SD card
	HAL_StatusTypeDef init_res;
	FRESULT mnt_res;
	int i = 0;

	do
	{
		//Initialize SD
		init_res = HAL_SD_Init(hsd);

		//Mount drive
		if(init_res == HAL_OK)
			mnt_res = f_mount(fs, "", 1);
		else
			HAL_Delay(1);

	} while(++i < _MAX_INIT_RETRY && ((init_res != HAL_OK) || (mnt_res != FR_OK)));

	if(i == _MAX_INIT_RETRY)
		return HAL_ERROR;

	//Configure card to 4bit mode
	return HAL_SD_ConfigWideBusOperation(hsd, SDIO_BUS_WIDE_4B);
}


/*
 * Remove power to the SD-Card
 * */
HAL_StatusTypeDef SD_Sleep(SD_HandleTypeDef* hsd)
{
	//Unmount drive
	if(f_mount(0, "", 0) != FR_OK)
		return HAL_ERROR;

	//Power off SD
	if(HAL_SD_DeInit(hsd) != HAL_OK)
		return HAL_ERROR;

	//Remove power
	PWR_Disable(PWR_SD);

	return HAL_OK;
}

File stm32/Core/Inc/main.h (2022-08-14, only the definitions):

#define BTN_SLEEP_Pin GPIO_PIN_0
#define BTN_SLEEP_GPIO_Port GPIOC
#define BTN_SLEEP_EXTI_IRQn EXTI0_IRQn
#define BAT_ADC_Pin GPIO_PIN_0
#define BAT_ADC_GPIO_Port GPIOA
#define EP_DC_Pin GPIO_PIN_4
#define EP_DC_GPIO_Port GPIOC
#define EP_CS_Pin GPIO_PIN_5
#define EP_CS_GPIO_Port GPIOC
#define EP_RST_Pin GPIO_PIN_0
#define EP_RST_GPIO_Port GPIOB
#define EP_BUSY_Pin GPIO_PIN_1
#define EP_BUSY_GPIO_Port GPIOB
#define PWR_3V3_EN_Pin GPIO_PIN_12
#define PWR_3V3_EN_GPIO_Port GPIOB
#define SD_D0_Pin GPIO_PIN_8
#define SD_D0_GPIO_Port GPIOC
#define SD_D1_Pin GPIO_PIN_9
#define SD_D1_GPIO_Port GPIOC
#define LED0_Pin GPIO_PIN_10
#define LED0_GPIO_Port GPIOA
#define PWR_SD_EN_Pin GPIO_PIN_15
#define PWR_SD_EN_GPIO_Port GPIOA
#define SD_D2_Pin GPIO_PIN_10
#define SD_D2_GPIO_Port GPIOC
#define SD_D3_Pin GPIO_PIN_11
#define SD_D3_GPIO_Port GPIOC
#define SD_CLK_Pin GPIO_PIN_12
#define SD_CLK_GPIO_Port GPIOC
#define SD_CMD_Pin GPIO_PIN_2
#define SD_CMD_GPIO_Port GPIOD
#define SD_DET_Pin GPIO_PIN_4
#define SD_DET_GPIO_Port GPIOB
#define LDR_SIG_Pin GPIO_PIN_8
#define LDR_SIG_GPIO_Port GPIOB
#define LDR_GND_Pin GPIO_PIN_9
#define LDR_GND_GPIO_Port GPIOB

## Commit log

2021-02-22 Added Schematic, Changed target MCU to STM32F405RGT6
    [Video-Frame.kicad_pcb, Video-Frame.kicad_sch]
2021-02-24 PCB Layout
    Changes in schematic
    + Fixed +3V3_SD Power NET
    + Changed 100uF electrolytic to 10uF tantalum (lower leakage current)
    [BOM.csv, CUI_DEVICES_UJ2-MIBH-G-SMT-TR.stp, MicroSD_Molex_1040310811.stp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]
2021-02-27 Updated schematic and PCB Layout
    + Added super capacitor on VDD
    + Added notes
    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
    [BOM.csv, FC0H473ZFTBR24.stp, Video-Frame.kicad_pcb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]
2021-02-28 Fixed D2 orientation in CPL file
    [Video-Frame.kicad_pcb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]
2021-03-01 Added enclosure 3D models
    [Back.stl, BatteryCover.stl, BatteryHolder.stl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]
2021-04-04 Code ported to STM32F405RGT
    [Video Frame Debug.cfg]
2021-04-05 Fixed 100 Ohm resistors part number
    [BOM.csv, Video-Frame.kicad_sch]
2021-04-10 Added standby mode
    STM32 enters standby mode after display update,
    DC-DC converter and SD powered off during standby,
    SD card communicates with 4bit bus
2021-06-12 FreeRTOS implementation
    Updated STM32CubeIDE to version 1.6.1
    Added battery_task: reads battery voltage every second
2021-06-13 Added console_task
    Implemented start/stop commands and low power mode timeout
2021-06-14 Added command task-info
    task-info prints information about created tasks (state, stack space, priority)
2021-06-26 Enabled DMA, SD still doesn't work
    [Video Frame.ioc, main.c]
2021-06-26 Porting to STM32CubeIDE 1.4.0
    Works only in release mode!!!
2021-06-28 Display update on wakeup interrupt
2022-08-14 Added light sensing
    The display now doesn't update if its too dark to see
    [Video Frame.ioc, main.c, main.h]

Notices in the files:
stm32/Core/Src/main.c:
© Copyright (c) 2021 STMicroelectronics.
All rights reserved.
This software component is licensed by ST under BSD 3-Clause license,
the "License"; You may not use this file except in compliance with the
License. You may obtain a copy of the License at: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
